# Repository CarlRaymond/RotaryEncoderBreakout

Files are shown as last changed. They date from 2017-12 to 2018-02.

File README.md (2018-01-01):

A breakout board for SparkFun's *Rotary Encoder - Illuminated (RGB)*
https://www.sparkfun.com/products/10982 (mfg. part number seems to be EC12PLRGB). The part includes an RGB LED, which is controlled by a WS2811 driver on the board. This turns it into an individually addressable RGB LED that can be part of a chain. See Adafruit's [The Magic of NeoPixels](https://learn.adafruit.com/adafruit-neopixel-uberguide/the-magic-of-neopixels?view=all).

The board can be used as an Arduino Uno shield, or on a breadboard. An extra header on the top brings out the data in and out lines, and allows selecting the WS2811 bitrate (either 400KHz or 800KHz). When used with an Arduino, the data in can come from pin PC3, or through the top side header. This lets it be used at the beginning, middle, or end of a chain of pixels.

Designed with KiCad. Includes sample Arduino code.

Bare board can be ordered from OSH Park: 
https://oshpark.com/shared_projects/EhRHmfJX

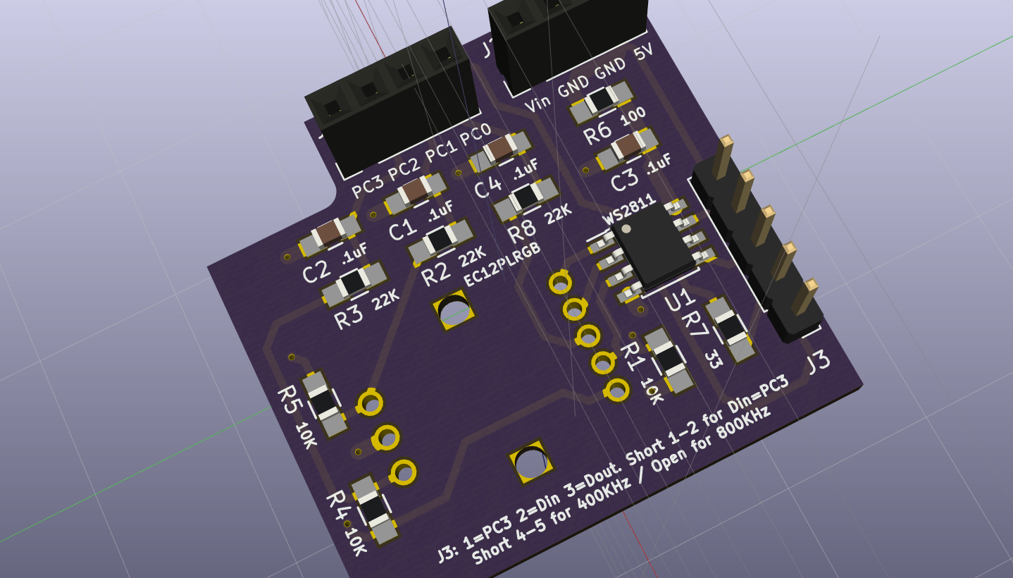
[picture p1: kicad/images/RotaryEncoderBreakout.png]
Image of breakout board

Image of schematic diagram

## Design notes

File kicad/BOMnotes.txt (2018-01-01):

Resistors and capacitors are generic; pads are oversize to work with 0805 or 1206 sizes.
Miscellaneous items:
2.54mm pitch pin headers, 9 positions total.

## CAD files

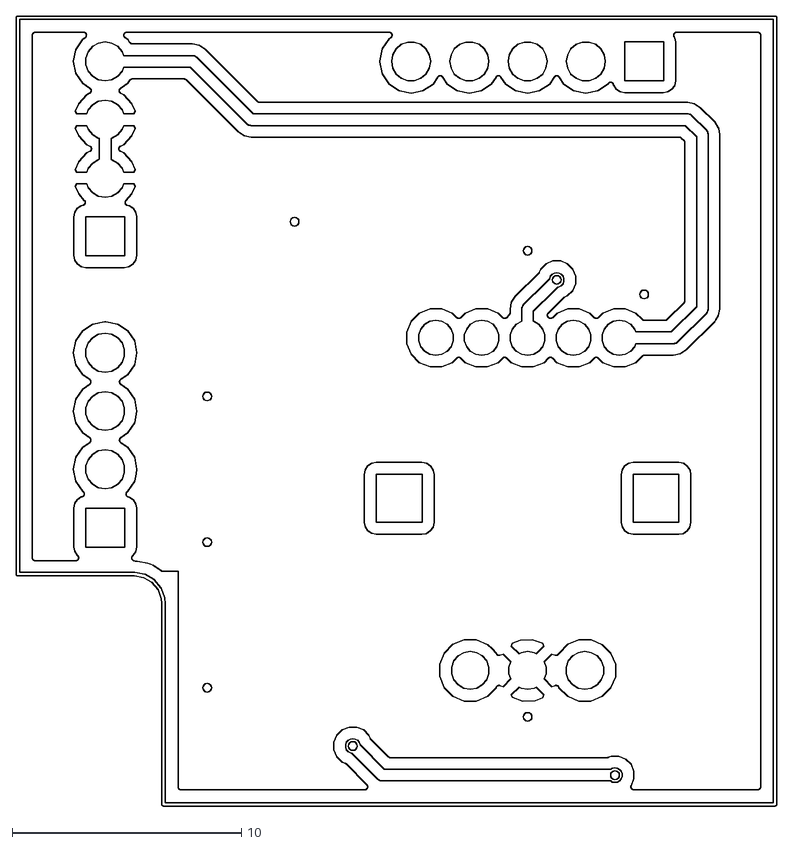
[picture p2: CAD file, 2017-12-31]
kicad/dxf/RotaryEncoderBreakout-B.Cu.dxf
33.2 x 34.4

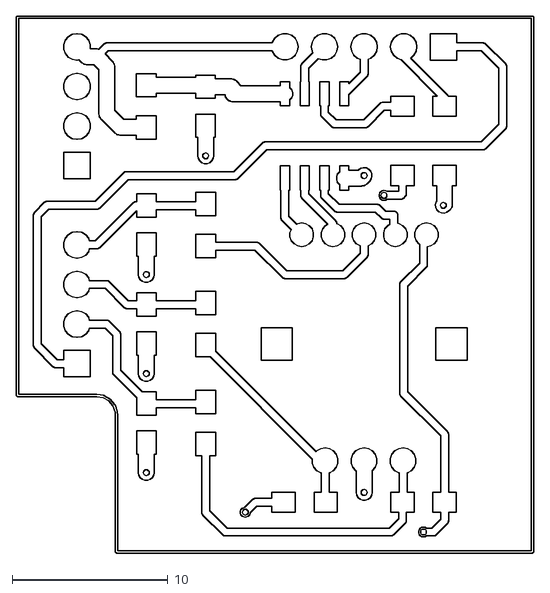
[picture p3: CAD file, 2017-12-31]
kicad/dxf/RotaryEncoderBreakout-F.Cu.dxf
33.2 x 34.4

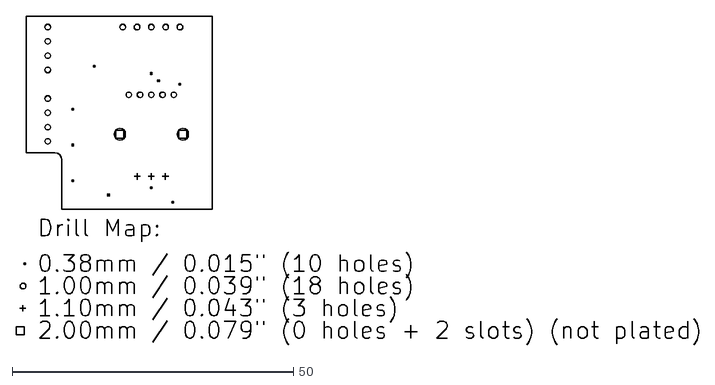
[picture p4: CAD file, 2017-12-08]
kicad/dxf/RotaryEncoderBreakout-drl_map.dxf
121.3 x 58.3

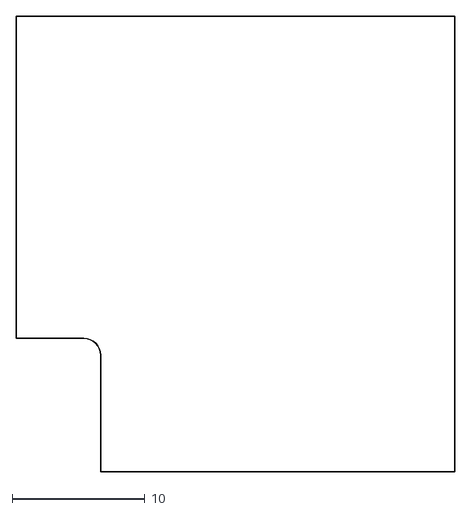
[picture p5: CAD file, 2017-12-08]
kicad/dxf/RotaryEncoderBreakout-Edge.Cuts.dxf
33.0 x 34.3

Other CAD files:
kicad/dxf/RotaryEncoderBreakout-B.Mask.dxf
kicad/dxf/RotaryEncoderBreakout-B.SilkS.dxf
kicad/dxf/RotaryEncoderBreakout-F.Mask.dxf
kicad/dxf/RotaryEncoderBreakout-F.SilkS.dxf

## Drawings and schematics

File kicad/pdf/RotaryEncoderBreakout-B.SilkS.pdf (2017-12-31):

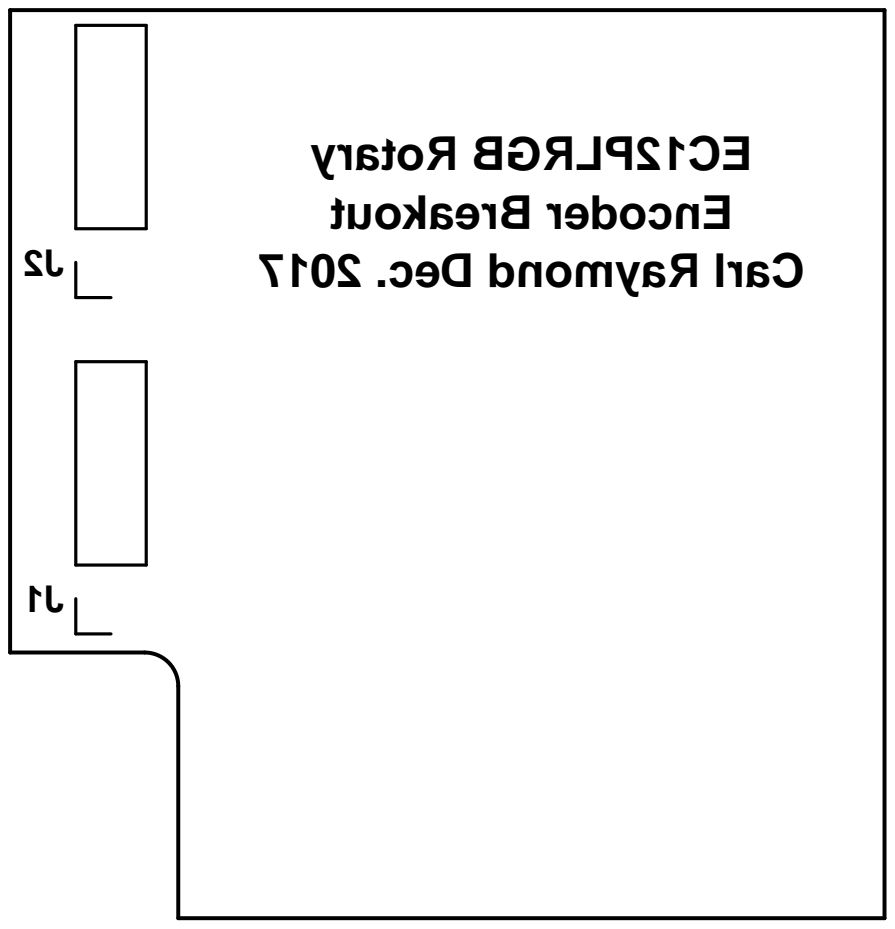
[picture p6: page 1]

EC12PLRGB Rotary Encoder Breakout Carl Raymond Dec. 2017

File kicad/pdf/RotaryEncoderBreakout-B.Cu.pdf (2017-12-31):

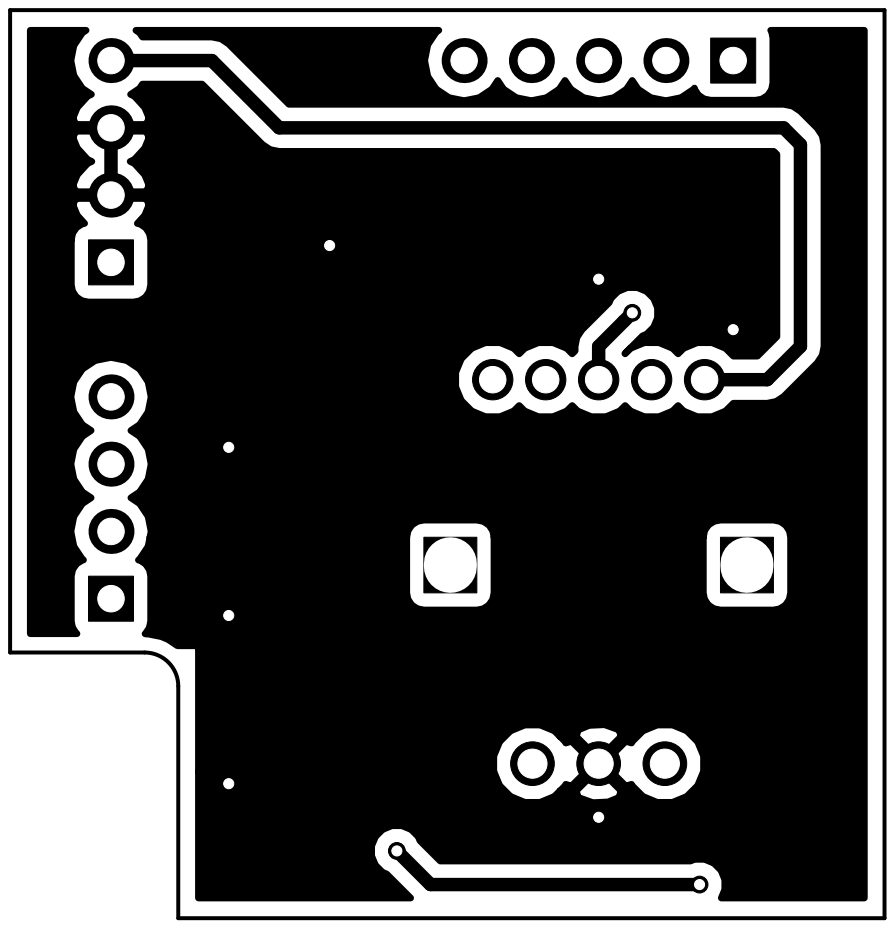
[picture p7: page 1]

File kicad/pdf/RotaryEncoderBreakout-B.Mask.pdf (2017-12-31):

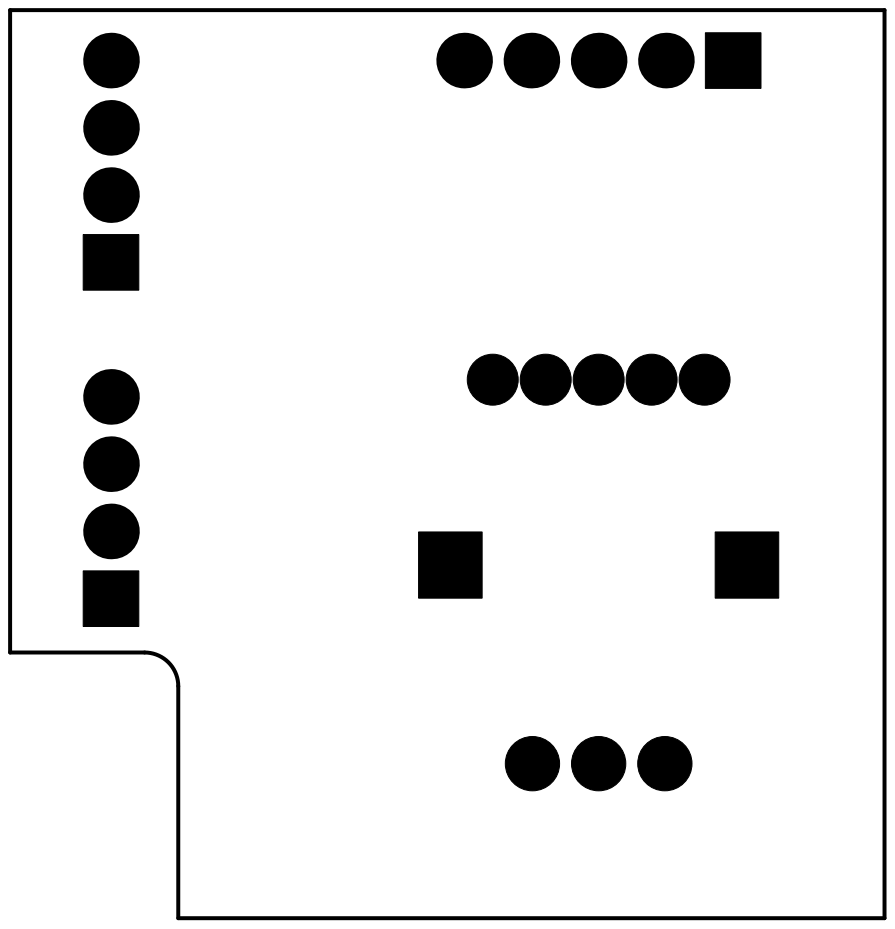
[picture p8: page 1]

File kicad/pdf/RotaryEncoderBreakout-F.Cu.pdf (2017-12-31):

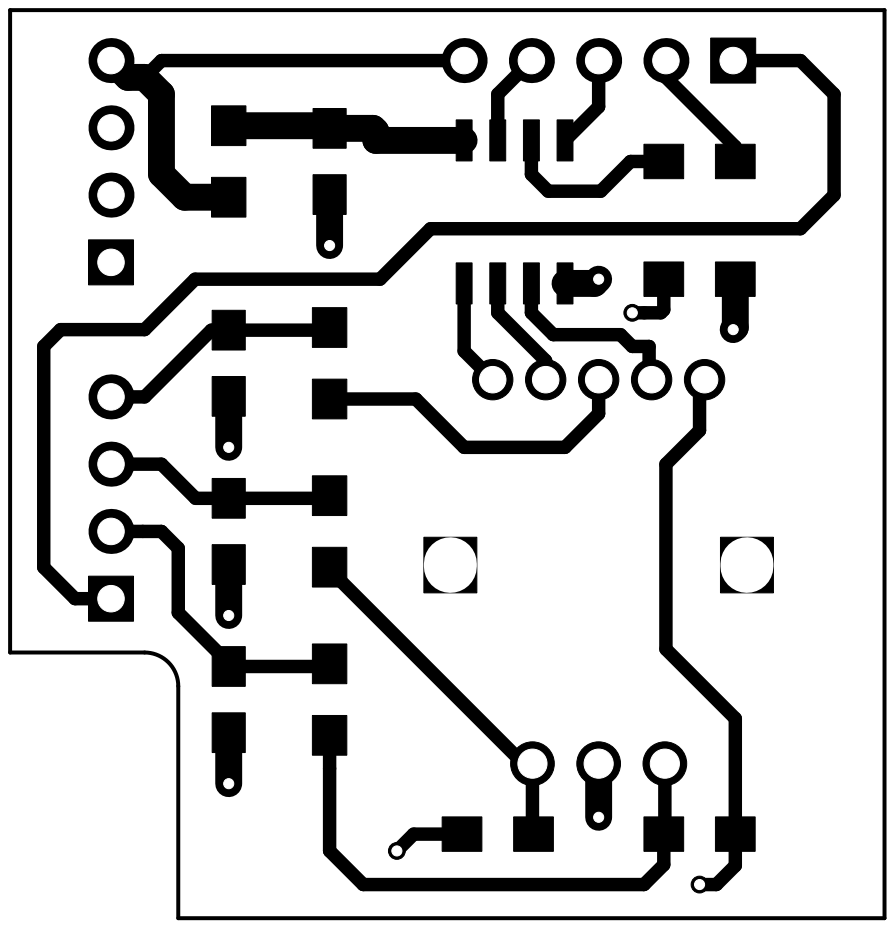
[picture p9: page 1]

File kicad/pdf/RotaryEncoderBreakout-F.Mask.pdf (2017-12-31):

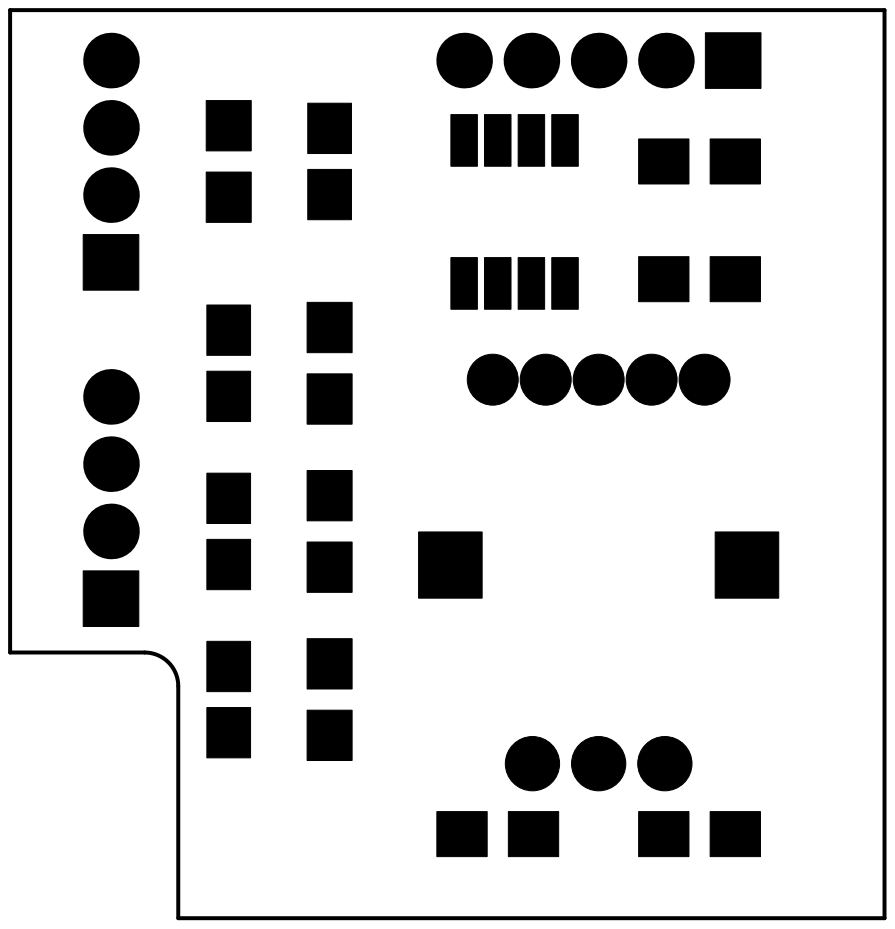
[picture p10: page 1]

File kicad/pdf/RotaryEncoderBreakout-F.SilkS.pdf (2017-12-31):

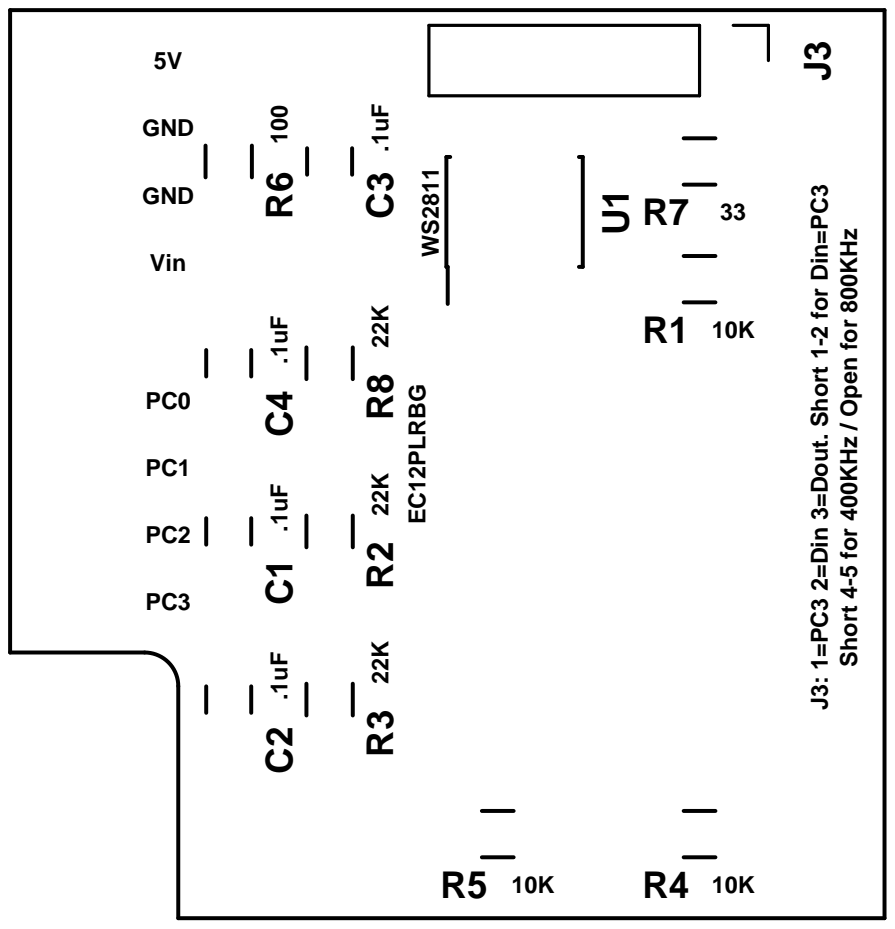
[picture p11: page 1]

J3: 1=PC3 2=Din 3=Dout. Short 1-2 for Din=PC3 Short 4-5 for 400KHz / Open for 800KHz PC0 PC1 PC2

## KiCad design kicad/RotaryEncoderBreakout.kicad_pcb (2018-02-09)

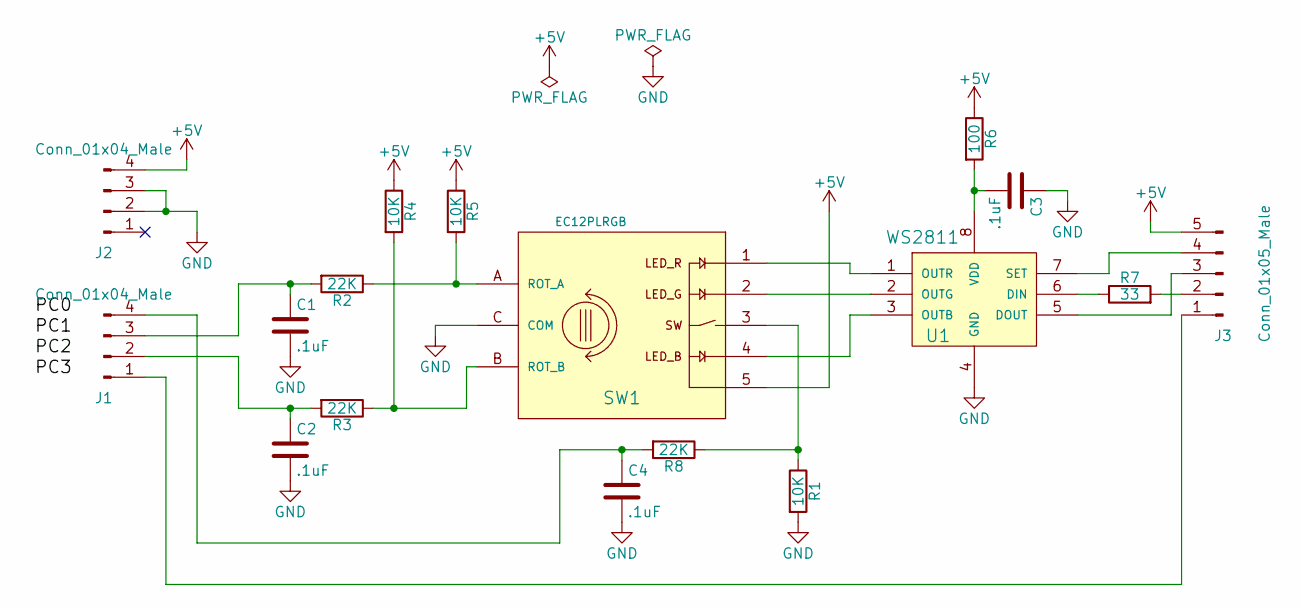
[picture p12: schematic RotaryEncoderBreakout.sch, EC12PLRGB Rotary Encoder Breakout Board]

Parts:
C1, C2, C3, C4: .1uF; C_0805_HandSoldering
J1, J2: Conn_01x04_Male; Socket_Strip_Straight_1x04_Pitch2.54mm
J3: Conn_01x05_Male; Pin_Header_Straight_1x05_Pitch2.54mm
R1, R4, R5: 10K; R_0805_HandSoldering
R2, R3, R8: 22K; R_0805_HandSoldering
R6: 100; R_0805_HandSoldering
R7: 33; R_0805_HandSoldering
SW1: EC12PLRGB; EC12PLRGB_Rotary_Encoder
U1: WS2811; SOIC-8_3.9x4.9mm_Pitch1.27mm

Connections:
+5V: J2.4, J3.5, R4.1, R5.1, R6.1, SW1.5
GND: C1.2, C2.2, C3.1, C4.2, J2.2, J2.3, R1.2, SW1.C (COM), U1.4 (GND)
unnamed: C1.1, J1.3, R2.2
unnamed: C2.1, J1.2, R3.2
unnamed: C3.2, R6.2, U1.8 (VDD)
unnamed: C4.1, J1.4, R8.2
unnamed: J1.1, J3.1
unnamed: J3.2, R7.2
unnamed: J3.3, U1.5 (DOUT)
unnamed: J3.4, U1.7 (SET)
unnamed: R1.1, R8.1, SW1.3
unnamed: R2.1, R5.2, SW1.A (ROT_A)
unnamed: R3.1, R4.2, SW1.B (ROT_B)
unnamed: R7.1, U1.6 (DIN)
unnamed: SW1.1, U1.1 (OUTR)
unnamed: SW1.2, U1.2 (OUTG)
unnamed: SW1.4, U1.3 (OUTB)

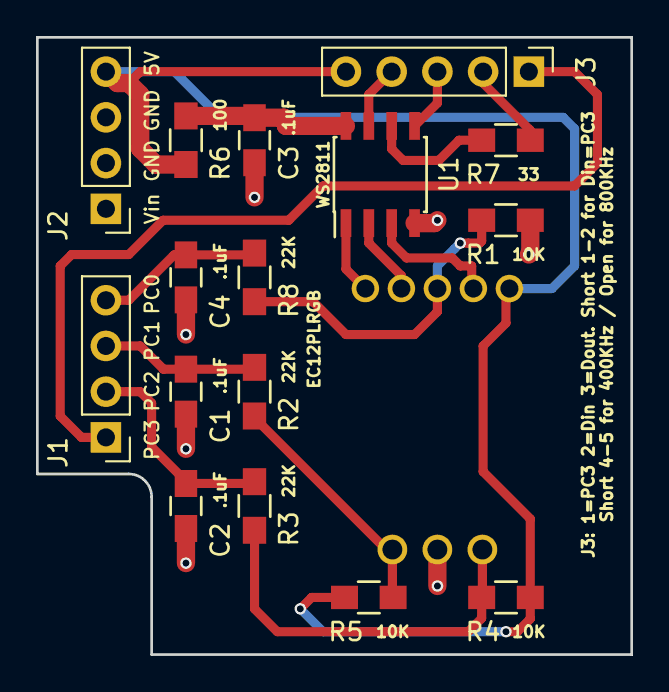
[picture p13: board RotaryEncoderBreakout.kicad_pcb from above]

Board: 2 copper layers, 33.0 x 34.3 mm, 17 parts (0 on the bottom side), 17 nets.

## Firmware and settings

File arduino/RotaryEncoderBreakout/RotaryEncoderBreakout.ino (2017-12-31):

// This demonstrates using the pin change interrupt to react to rotating
// the control and pressing the button. The pushbutton and the two phases
// of the encoder are all connected to port C. A bit change on any of those
// pins will invoke the port C pin change ISR, whose job is to sample the
// new values, and compare to the old values to figure out what happened.
//
// The ISR sends output to the serial port for viewing with the Serial Monitor.
//
// The main processing loop uses the Adafruit Neopixel library to continually
// change the color of the pixel. Operating the control does not affect the
// pixel behavior.
// 
// Pin assignments:
//
// Encoder pushbutton, PORTC bit 0
#define PUSHBUTTON_PIN 14
// Encoder phase A, PORTC bit 1
#define PHASEA_PIN 15
// Encoder phase B, PORTC bit 2
#define PHASEB_PIN 16
// Data out to WS2811, PORTC bit 3
#define LED_PIN 17

#include <Adafruit_NeoPixel.h>
#ifdef __AVR__
  #include <avr/power.h>
#endif

// Parameter 1 = number of pixels in strip
// Parameter 2 = Arduino pin number (most are valid)
// Parameter 3 = pixel type flags, add together as needed:
//   NEO_KHZ800  800 KHz bitstream (most NeoPixel products w/WS2812 LEDs)
//   NEO_KHZ400  400 KHz (classic 'v1' (not v2) FLORA pixels, WS2811 drivers)
//   NEO_GRB     Pixels are wired for GRB bitstream (most NeoPixel products)
//   NEO_RGB     Pixels are wired for RGB bitstream (v1 FLORA pixels, not v2)
//   NEO_RGBW    Pixels are wired for RGBW bitstream (NeoPixel RGBW products)
Adafruit_NeoPixel strip = Adafruit_NeoPixel(1, LED_PIN, NEO_GRB + NEO_KHZ400);

// Rotating clockwise will increase value; counterclockwise will decrease it.
volatile byte encoderValue = 0;

void setup() {
  pinMode(PUSHBUTTON_PIN, INPUT);
  pinMode(PHASEA_PIN, INPUT);
  pinMode(PHASEB_PIN, INPUT);
  pinMode(LED_PIN, OUTPUT);

  Serial.begin(230400);

  // Enable pin change interrupts
  *digitalPinToPCMSK(PUSHBUTTON_PIN) |= bit (digitalPinToPCMSKbit(14));  // enable pin
  *digitalPinToPCMSK(PHASEA_PIN) |= bit (digitalPinToPCMSKbit(15));  // enable pin
  *digitalPinToPCMSK(PHASEB_PIN) |= bit (digitalPinToPCMSKbit(16));  // enable pin

  // Clear outstanding interrupts and enable. Only necessary to reference one
  // pin since all configured pins generate the same interrupt.
  PCIFR  |= bit (digitalPinToPCICRbit(PUSHBUTTON_PIN));
  PCICR  |= bit (digitalPinToPCICRbit(PUSHBUTTON_PIN));
  
  // Commence Neopixeling
  strip.begin();
  strip.show(); // Initialize all pixels to 'off'

}

void loop() {
  // Some example procedures showing how to display to the pixels:
  colorWipe(strip.Color(255, 0, 0), 16); // Red
  colorWipe(strip.Color(0, 255, 0), 16); // Green
  colorWipe(strip.Color(0, 0, 255), 17); // Blue
  colorWipe(strip.Color(127, 0, 127), 16); //Purple
  rainbow(20);
  rainbowCycle(20);
}

// Pin change interrupt for PORT C: Button was pressed/released, or
// the encoder was rotated.
// One click of the wheel cycles through all four states of the quadrature
// encoding, and this ISR is invoked four times. The variable encoderValue
// is only incremented or decremented once per click.
ISR(PCINT1_vect)
{
  // Holds previous currentEncoderData read from encoder port
  static byte lastEncoderData = 0x00;
  // Shift register for decoding quadrature transitions in lower 4 bits
  static byte quadratureRegister = 0x00;

  // Helps with cleaner output on the serial port, by adding a newline
  // at intervals.
  static int newlineCountdown = 80;

  // Get current data on PORTC bits 0-2; mask off the rest.
  byte currentEncoderData = PINC & 0x07;

  // Figure out what changed
  byte diff = currentEncoderData ^ lastEncoderData;

  // Did pushbutton bit change?
  if (diff & 0x01) {
    // Up or down?
    if (currentEncoderData & 0x01)
      Serial.print('D');  // Down
    else
      Serial.print('U');  // Up
  }

  // Did quadrature bits change?
  if (diff & 0x06) {
    // Shift prior quadrature bits left, and read current bits in; mask off the rest
    byte encBits = (PINC & 0x06) >> 1;
    quadratureRegister = ((quadratureRegister << 2) | encBits ) & 0x0f;

    // Figure out what happened.
    switch (quadratureRegister) {
      // Clockwise cases:
      case 0x01:  // 00 -> 01
      case 0x07:  // 01 -> 11
      case 0x0e:  // 11 -> 10
      case 0x08:  // 10 -> 00
        Serial.print('>');

        // Only increment value 1 time out of 4
        if ((encBits & 0x03) == 0x03) {
          encoderValue++;
          Serial.print(encoderValue);
        }
        break;

      // Counterclockwise cases:
      case 0x0b:  // 10 -> 11
      case 0x0d:  // 11 -> 01
      case 0x04:  // 01 -> 00
      case 0x02:  // 00 -> 10
        Serial.print('<');

        // Only decrement the value 1 time out of 4
        if ((encBits & 0x03) == 0x03) {
          encoderValue--;
          Serial.print(encoderValue);
        }
        break;

      // Other cases are invalid. Ignore.
      default:
        Serial.print('-');
        break;
    } 
  }

  // Remember this state for next time through.
  lastEncoderData = currentEncoderData;

  // Time for a newline?
  if (--newlineCountdown == 0) {
    Serial.println();
    newlineCountdown = 80;
  }
}

// These are from the NeoPixel demo library

// Fill the dots one after the other with a color
void colorWipe(uint32_t c, uint8_t wait) {
  for(uint16_t i=0; i<strip.numPixels(); i++) {
    strip.setPixelColor(i, c);
    strip.show();
    delay(wait);
    strip.setPixelColor(i, 0);
  }
}

void rainbow(uint8_t wait) {
  uint16_t i, j;

  for(j=0; j<256; j++) {
    for(i=0; i<strip.numPixels(); i++) {
      strip.setPixelColor(i, Wheel((i+j) & 255));
    }
    strip.show();
    delay(wait);
  }
}

// Slightly different, this makes the rainbow equally distributed throughout
void rainbowCycle(uint8_t wait) {
  uint16_t i, j;

  for(j=0; j<256*5; j++) { // 5 cycles of all colors on wheel
    for(i=0; i< strip.numPixels(); i++) {
      strip.setPixelColor(i, Wheel(((i * 256 / strip.numPixels()) + j) & 255));
    }
    strip.show();
    delay(wait);
  }
}


// Input a value 0 to 255 to get a color value.
// The colours are a transition r - g - b - back to r.
uint32_t Wheel(byte WheelPos) {
  WheelPos = 255 - WheelPos;
  if(WheelPos < 85) {
    return strip.Color(255 - WheelPos * 3, 0, WheelPos * 3);
  }
  if(WheelPos < 170) {
    WheelPos -= 85;
    return strip.Color(0, WheelPos * 3, 255 - WheelPos * 3);
  }
  WheelPos -= 170;
  return strip.Color(WheelPos * 3, 255 - WheelPos * 3, 0);
}

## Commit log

2017-12-07 Initial checkin
    [RotaryEncoderBreakout.kicad_pcb, RotaryEncoderBreakout.sch]
2017-12-07 Layout complete
    [RotaryEncoderBreakout.kicad_pcb, RotaryEncoderBreakout.sch]
2017-12-07 Better silkscreen
    [RotaryEncoderBreakout.kicad_pcb]
2017-12-08 Final layout
    [RotaryEncoderBreakout-B.Cu.dxf, RotaryEncoderBreakout-B.Mask.dxf, RotaryEncoderBreakout-B.SilkS.dxf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]
2017-12-11 Created local symbol and footprint libraries for portability
2017-12-11 Changed symbol and library references to local copy
    [RotaryEncoderBreakout.kicad_pcb, RotaryEncoderBreakout.sch]
2017-12-13 Add README.md
    [RotaryEncoderBreakout.kicad_pcb]
2017-12-15 Add image of schematic.
    [RotaryEncoderBreakout.sch]
2017-12-16 Silkscreen refinement
    [RotaryEncoderBreakout.kicad_pcb]
2017-12-30 Update component values
    [RotaryEncoderBreakout.kicad_pcb, RotaryEncoderBreakout.sch]
2017-12-30 Added Arduino code
    [RotaryEncoderBreakout-B.Cu.dxf, RotaryEncoderBreakout-B.Mask.dxf, RotaryEncoderBreakout-B.SilkS.dxf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]
2017-12-31 Final design
    Add Arduino code, datasheets, and update gerber/pdf/dxf/image output.
    [RotaryEncoderBreakout-B.Cu.dxf, RotaryEncoderBreakout-B.Mask.dxf, RotaryEncoderBreakout-B.SilkS.dxf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]
2017-12-31 Update schematic image
2018-01-01 Add bill of materials
    [RotaryEncoderBreakout.sch]
2018-02-09 Change J1 and J2 to socket headers
    Change J1 & J2 from pin headers to Arduino-style socket strips.
    [RotaryEncoderBreakout.kicad_pcb, RotaryEncoderBreakout.sch]
2018-02-09 Replace pin headers with socket strips
    [RotaryEncoderBreakout.kicad_pcb]
